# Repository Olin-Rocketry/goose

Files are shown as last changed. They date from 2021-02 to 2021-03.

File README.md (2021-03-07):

# G.O.O.S.E
**G**reat **O**verview **O**f **S**TM **E**lectronics

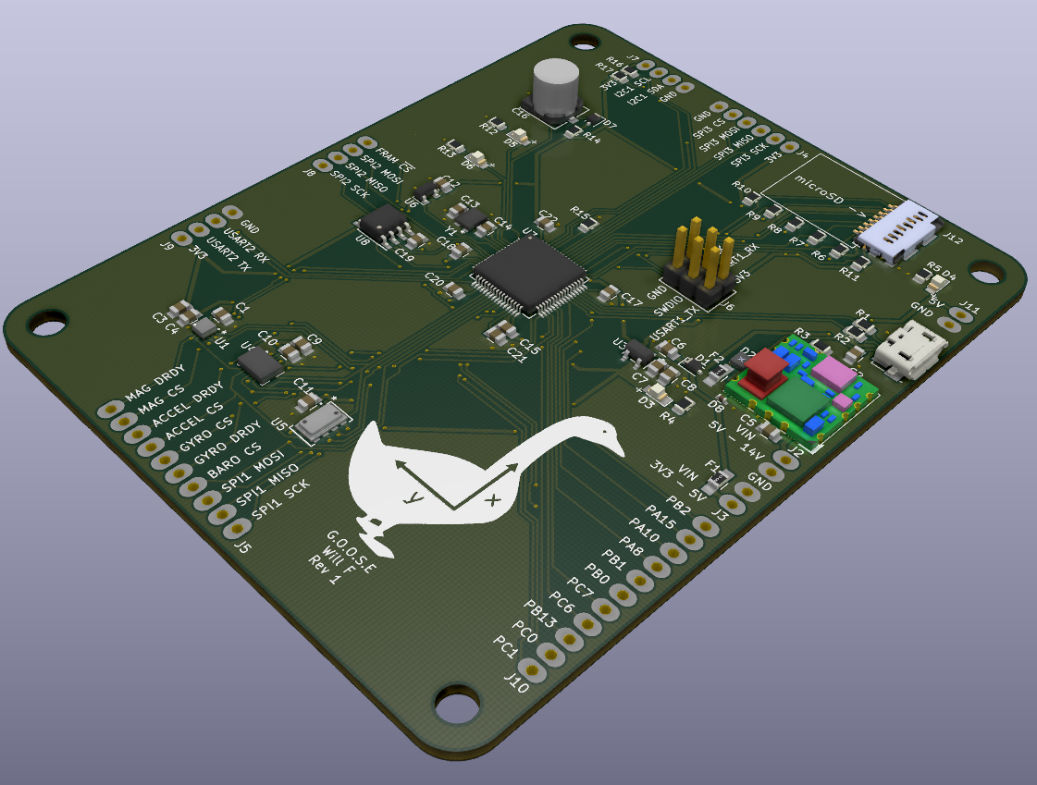
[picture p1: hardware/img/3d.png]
3d render


The overarching goal of this project is to establish the foundation for designing and coding boards with more advanced stm32f-series microcontrollers. These microcontrollers are arm-based, super common in industry and hobbyist projects, have a large community of support, and a ton of features avr chips don't have like:
- usb support
- real time clocks
- high clock speeds (>100Mhz)
- SDIO communication support
- debugging ports
- Direct Memory Access (DMA)

## Development Board
As a development board the primary focus is on testing new hardware (stm32, sensors, power-converts, communication lines, memory, etc). As a result, this board has a ton of pinouts for direct access to almost every pin on the stm32 and all of the communication ports. This board also has a wide voltage input range (3V3 to 14V) in order to allow for a variety of input sources (power supply, battery, usb port, etc). The following is a list of key components on the board.

- **Microcontroller**
	- STM32F401RCT6
- **Sensors**
	- IMU--BMI088
	- Magnetometer--LIS3MDLTR
	- Barometer--MS560702BA03-50
- **Non-Volatile Memory**
	- FM25L04B-G
- **Connection**
	- Micro-SD
	- Debugging/Programming Port 
	- Micro-USB
	- SPI, I2C, UART pinouts
	- Other pinouts
- **Power**
	- Input
		- 3V3 to 14V
	- Output
		- 5V (buck converter)
		- 3V3 (Low Droput Regulator)

## Schematic
The full schematic pdf view can be viewed [here](/hardware/dev_board.pdf)



## Kicad Parts & Footprints
Currently, most of the parts and footprints are located in a [personal library](https://github.com/wFairmanOlin/kicad_parts). I will transition the necessary files to the olin rocketry library when the project is closer to completion.

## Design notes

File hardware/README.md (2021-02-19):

## Accessing Parts Folder 

For now, if you want to access the parts for this board, clone this [repo](https://github.com/wFairmanOlin/kicad_parts) and add a path pointing to `personal.lib` similar to this:

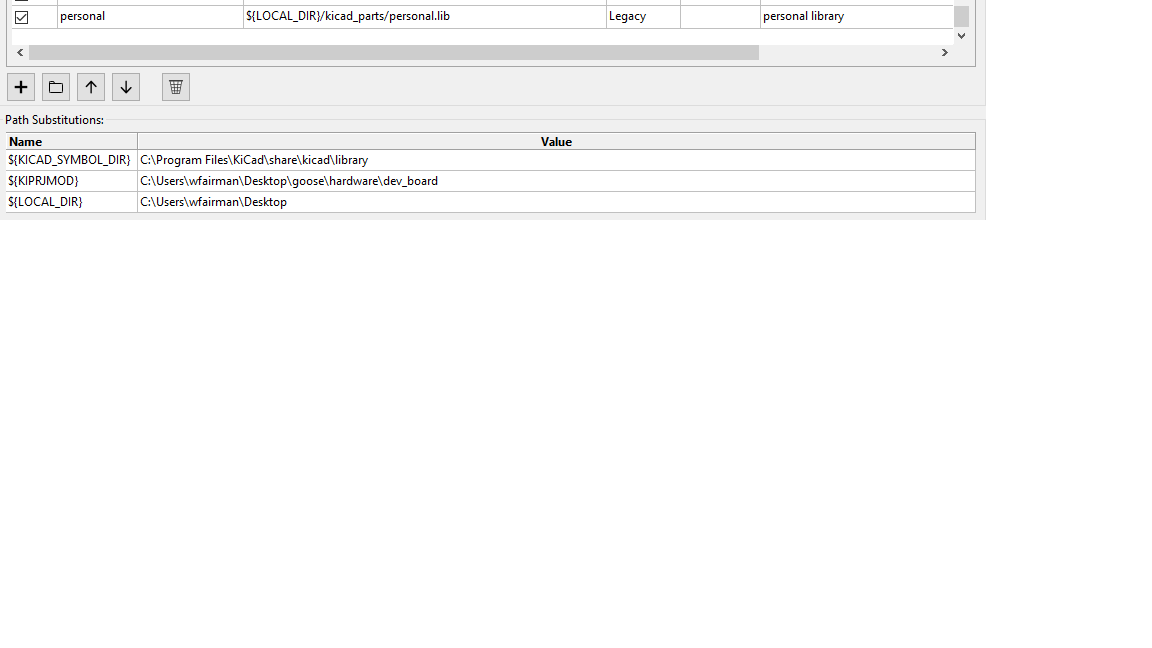
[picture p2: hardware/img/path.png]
path


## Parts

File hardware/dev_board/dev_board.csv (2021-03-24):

Designator | Quantity | Comment | Footprint | MPN | DPN
C13 C14 | 2 | C_8p | C_0805 | CC0805DRNPO9BN8R0 | 311-1097-1-ND
C16 | 1 | C_220u | UWT0G221MCL6GS | UWT0G221MCL6GS | 493-9872-1-ND
C15 C17 | 2 | C_4u7 | C_0805 | GRM21BR71C475KE51L | 490-14466-1-ND
C1 C2 C4 C8 C9 C10 C11 C12 C18 C19 C20 C21 C22 | 13 | C_0u1 | C_0805 | 08055C104JAT2A | 478-3352-1-ND
C3 | 1 | C_1u | C_0805 | C0805C105Z4VACTU | 399-8011-1-ND
C5 | 1 | C_22u | C_0805 | GRM21BR61E226ME44K | 490-14661-1-ND
C6 C7 | 2 | C_10u | C_0805 | GRM21BR61E106KA73K | 490-16824-1-ND
D2 | 1 | D_Schottky_x2_20V | SOT1061 | PMEG2020CPA,115 | 1727-5194-1-ND
D3 D4 D5 D6 | 4 | LED_0805_Green | LED_0805 | LG R971-KN-1 | 475-1410-1-ND
D1 D7 | 2 | D_Schottky_10V_3A | D_SOD-323F | PMEG1030EJ,115 | 1727-3852-1-ND
D8 | 1 | TVS_DIODE_14V | C_0402 | PESD0402-140 | PESD0402-140CT-ND
F1 F2 | 2 | PTC_6V_1A | R_0805 | 0ZCK0050FF2E | 507-1813-1-ND
J1 | 1 | Micro_USB | Molex_47346-0001 | 473460001 | WM17141CT-ND
J10 | 1 | Conn_01x11 | none | none | none
J12 | 1 | 105162-0001 | 105162-0001 | 1051620001 | WM14405CT-ND
J2 J3 J11 | 3 | do not populate | none | none | none
J4 | 1 | do not populate | none | none | none
J5 | 1 | do not populate | none | none | none
J6 | 1 | Conn_02x03 | TSW-103-07-F-D | TSW-103-07-F-D | SAM10846-ND
J7 J8 J9 | 3 | do not populate | none | none | none
R1 R2 | 2 | R_22 | R_0805 | CR0805-FX-22R0ELF | CR0805-FX-22R0ELFCT-ND
R14 | 1 | R_1K | R_0805 | RC0805JR-071KL | 311-1.0KARCT-ND
R15 R16 R17 | 3 | R_10K | R_0805 | RC0805FR-0710KL | 311-10.0KCRCT-ND
R3 | 1 | R_2K18 | R_0805 | RT0805BRD072K18L | 13-RT0805BRD072K18LCT-ND
R4 R12 R13 | 3 | R_51.1 | R_0805 | RMCF0805FT51R1 | RMCF0805FT51R1CT-ND
R5 | 1 | R_120 | R_0805 | CRGCQ0805F120R | A129738CT-ND
R6 R7 R8 R9 R10 R11 | 6 | R_100K | R_0805 | RC0805FR-07100KL | 311-100KCRCT-ND
U1 | 1 | LIS3MDLTR | LIS3MDLTR | LIS3MDLTR | 497-13892-1-ND
U2 | 1 | OKL-T_1-W12P-C | OKL-T1-W12P-C | OKL-T/1-W12P-C | 811-3418-1-ND
U3 | 1 | LDO_600MA | SOT-25_DIO | AP7365-33WG-7 | AP7365-33WG-7DICT-ND
U4 | 1 | BMI088 | BMI088 | BMI088 | 828-1082-1-ND
U5 | 1 | Barometer_MS5607 | MS561101BA03-50 | MS560702BA03-50 | 223-1198-1-ND
U6 | 1 | MCP131T-300E_TT | SOT-23 | MCP131T-300E/TT | MCP131T-300E/TTCT-ND
U7 | 1 | STM32F401RCTx | LQFP-64_10x10mm_P0.5mm | STM32F401RCT6 | 497-14047-ND
U8 | 1 | FRAM_4K | SOIC-8_3.9x4.9mm_Pitch1.27mm | FM25L04B-G | 428-3209-ND
Y1 | 1 | Crystal_24MHZ | STD-CSR-1 | NX3225SA-24.000M-STD-CSR-1 | 644-1052-1-ND

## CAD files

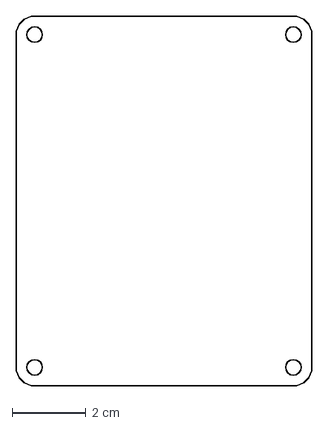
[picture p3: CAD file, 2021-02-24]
hardware/dev_board/circuitBoard v2.dxf
8.00 x 10.0 cm

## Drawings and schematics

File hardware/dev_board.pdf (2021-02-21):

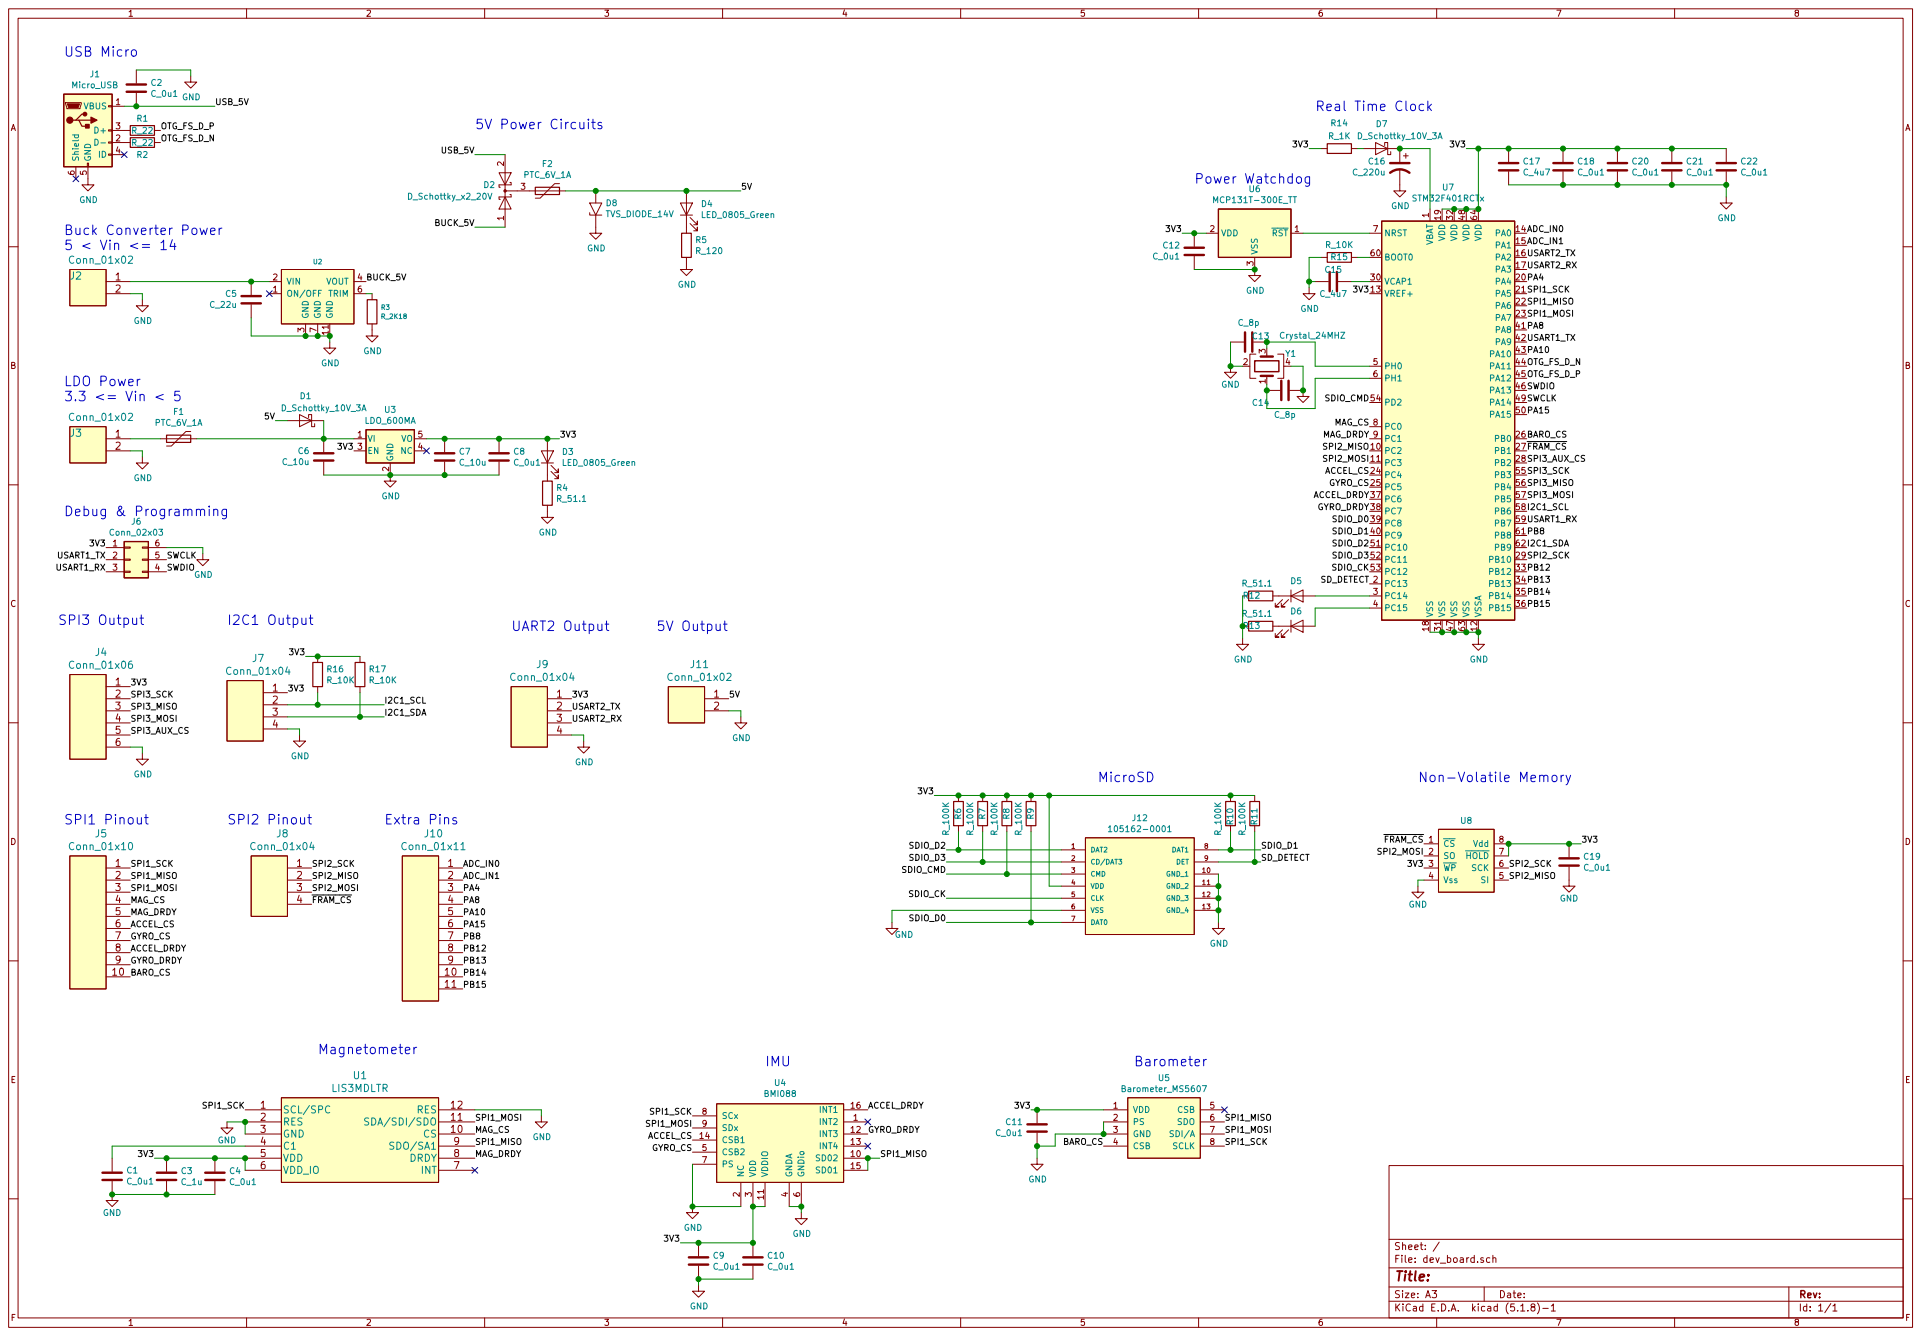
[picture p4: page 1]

1 VCAP1 30 VDD 19 VDD 32 VDD 48 VDD 64 VREF+ 13 VSS 18 VSS 31 VSS 47 VSS 63 VSSA 12 U7 STM32F401RCTx

6 PS 7 SCx 8 SDx 9 U4 BMI088 GND

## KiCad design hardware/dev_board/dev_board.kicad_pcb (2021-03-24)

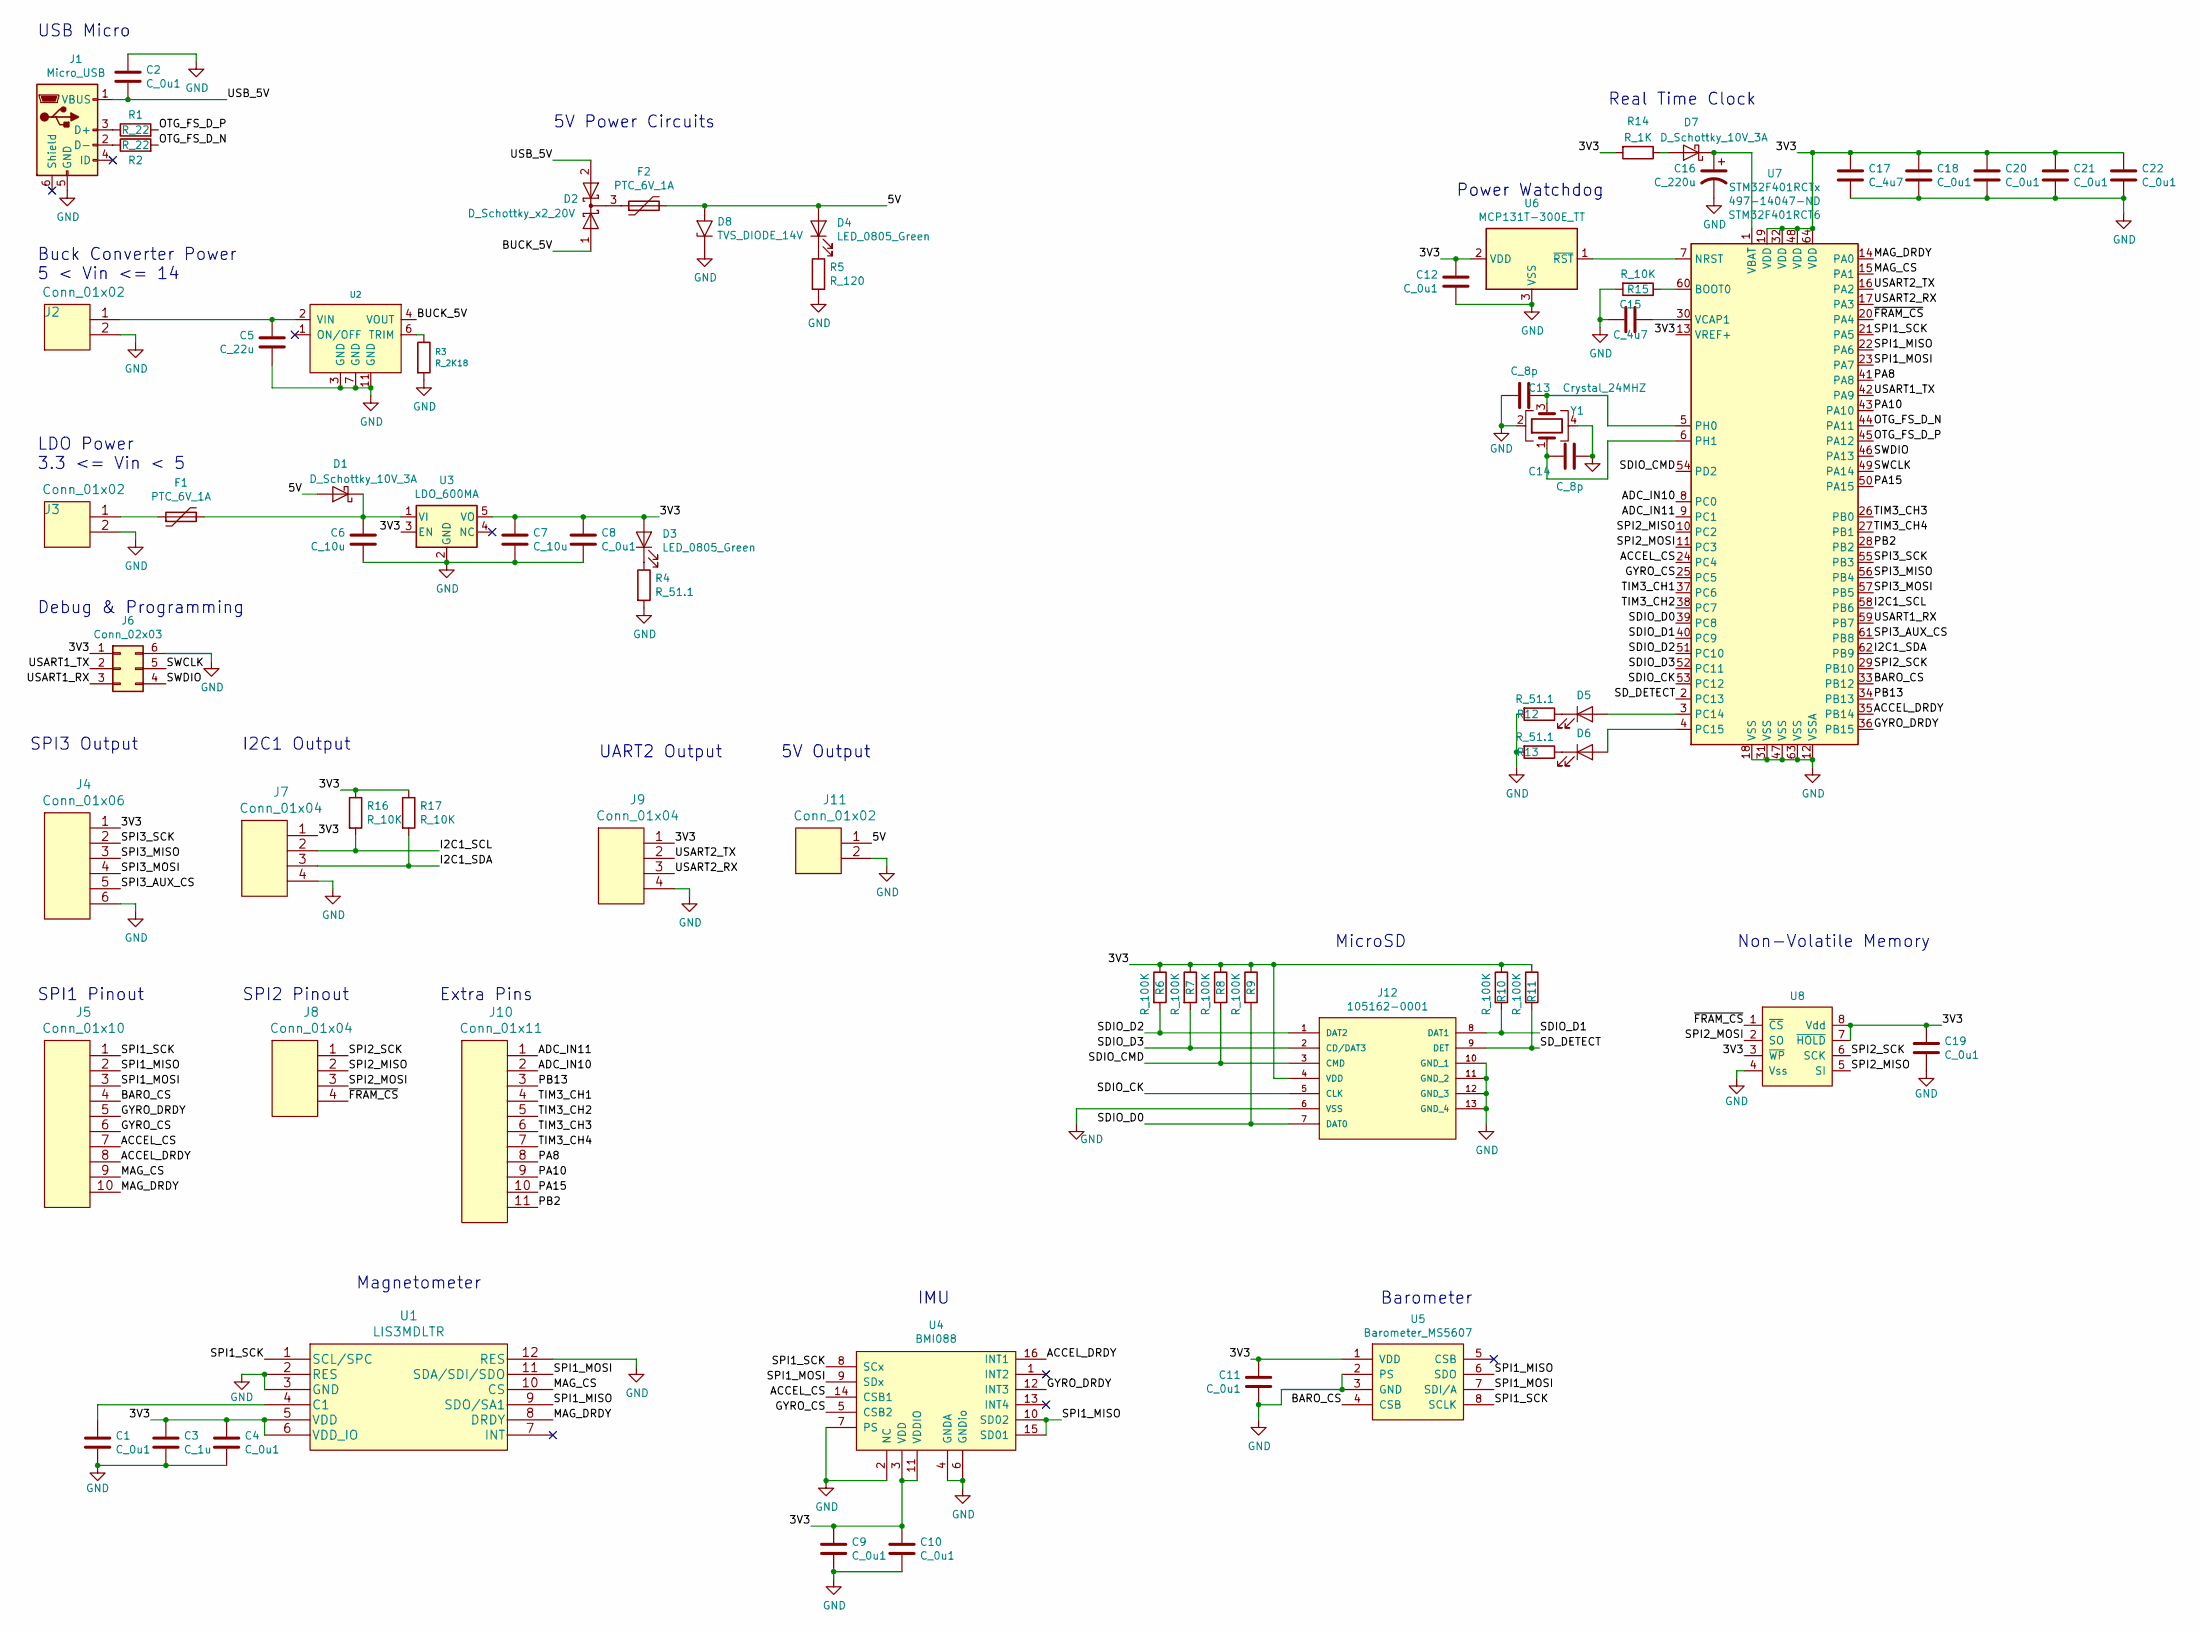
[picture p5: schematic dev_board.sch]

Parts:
C1, C2, C4, C8, C9, C10, C11, C12, C18, C19, C20, C21, C22: C_0u1; C_0805
C3: C_1u; C_0805
C5: C_22u; C_0805
C6, C7: C_10u; C_0805
C13, C14: C_8p; C_0805
C15, C17: C_4u7; C_0805
C16: C_220u; UWT0G221MCL6GS; MPN UWT0G221MCL6GS
D1, D7: D_Schottky_10V_3A; D_SOD-323F; MPN PMEG1030EJ,115
D2: D_Schottky_x2_20V; SOT1061; MPN PMEG2020CPA,115
D3, D4, D5, D6: LED_0805_Green; LED_0805; MPN LG R971-KN-1
D8: TVS_DIODE_14V; C_0402
F1, F2: PTC_6V_1A; R_0805_HandSoldering; MPN 0ZCK0050FF2E
J1: Micro_USB; USB_Micro-B_Molex_47346-0001
J2, J3, J11: Conn_01x02; header_01x02
J4: Conn_01x06; header_01x06
J5: Conn_01x10; header_01x10
J6: Conn_02x03; TSW-103-07-F-D; MPN TSW-103-07-F-D
J7, J8, J9: Conn_01x04; header_01x04
J10: Conn_01x11; header_01x11
J12: 105162-0001; MPN 1051620001
R1, R2: R_22; R_0805; MPN CR0805-FX-22R0ELF
R3: R_2K18; R_0805; MPN RT0805BRD072K18L
R4, R12, R13: R_51.1; R_0805; MPN RMCF0805FT51R1
R5: R_120; R_0805
R6, R7, R8, R9, R10, R11: R_100K; R_0805; MPN RC0805FR-07100KL
R14: R_1K; R_0805
R15, R16, R17: R_10K; R_0805; MPN RC0805FR-0710KL
U1: LIS3MDLTR
U2: OKL-T_1-W12P-C; OKL-T1-W12P-C; MPN OKL-T/1-W12P-C
U3: LDO_600MA; SOT-25_DIO; MPN AP7365-33WG-7
U4: BMI088
U5: Barometer_MS5607; MS561101BA03-50; MPN MS560702BA03-50
U6: MCP131T-300E_TT; SOT-23
U7: STM32F401RCTx; LQFP-64_10x10mm_Pitch0.5mm; MPN STM32F401RCT6
U8: FRAM_4K; SOIC-8_3.9x4.9mm_Pitch1.27mm; MPN FM25L04B-G
Y1: Crystal_24MHZ; NX3225SA-24.000M-STD-CSR-1; MPN NX3225SA-24.000M-STD-CSR-1

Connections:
/3V3: C3.1, C4.1, C7.1, C8.1, C9.1, C10.1, C11.2, C12.2, C17.1, C18.1, C19.1, C20.1, C21.1, C22.1, D3.2 (A), J4.1, J6.1, J7.1, J9.1, J12.4 (VDD), R6.1, R7.1, R8.1, R9.1, R10.1, R11.1, R14.2, R16.1, R17.1, U1.5 (VDD), U1.6 (VDD_IO), U3.3 (EN), U3.5 (VO), U4.3 (VDD), U4.11 (VDDIO), U5.1 (VDD), U6.2 (VDD), U7.13 (VREF+), U7.19 (VDD), U7.32 (VDD), U7.48 (VDD), U7.64 (VDD), U8.3 (~WP), U8.7 (~HOLD), U8.8 (Vdd)
/5V: D1.2 (A), D4.2 (A), D8.2 (A2), F2.2, J11.1
/ACCEL_CS: J5.7, U4.14 (CSB1), U7.24 (PC4)
/ACCEL_DRDY: J5.8, U4.16 (INT1), U7.35 (PB14)
/ADC_IN10: J10.2, U7.8 (PC0)
/ADC_IN11: J10.1, U7.9 (PC1)
/BARO_CS: J5.4, U5.4 (CSB), U7.33 (PB12)
/BUCK_5V: D2.1 (A), U2.4 (VOUT)
/GYRO_CS: J5.6, U4.5 (CSB2), U7.25 (PC5)
/GYRO_DRDY: J5.5, U4.12 (INT3), U7.36 (PB15)
/I2C1_SCL: J7.2, R16.2, U7.58 (PB6)
/I2C1_SDA: J7.3, R17.2, U7.62 (PB9)
/MAG_CS: J5.9, U1.10 (CS), U7.15 (PA1)
/MAG_DRDY: J5.10, U1.8 (DRDY), U7.14 (PA0)
/OTG_FS_D_N: R2.2, U7.44 (PA11)
/OTG_FS_D_P: R1.2, U7.45 (PA12)
/PA8: J10.8, U7.41 (PA8)
/PA10: J10.9, U7.43 (PA10)
/PA15: J10.10, U7.50 (PA15)
/PB2: J10.11, U7.28 (PB2)
/PB13: J10.3, U7.34 (PB13)
/SDIO_CK: J12.5 (CLK), U7.53 (PC12)
/SDIO_CMD: J12.3 (CMD), R8.2, U7.54 (PD2)
/SDIO_D0: J12.7 (DAT0), R9.2, U7.39 (PC8)
/SDIO_D1: J12.8 (DAT1), R10.2, U7.40 (PC9)
/SDIO_D2: J12.1 (DAT2), R6.2, U7.51 (PC10)
/SDIO_D3: J12.2 (CD/DAT3), R7.2, U7.52 (PC11)
/SD_DETECT: J12.9 (DET), R11.2, U7.2 (PC13)
/SPI1_MISO: J5.2, U1.9 (SDO/SA1), U4.10 (SD02), U4.15 (SD01), U5.6 (SDO), U7.22 (PA6)
/SPI1_MOSI: J5.3, U1.11 (SDA/SDI/SDO), U4.9 (SDx), U5.7 (SDI/A), U7.23 (PA7)
/SPI1_SCK: J5.1, U1.1 (SCL/SPC), U4.8 (SCx), U5.8 (SCLK), U7.21 (PA5)
/SPI2_MISO: J8.2, U7.10 (PC2), U8.5 (SI)
/SPI2_MOSI: J8.3, U7.11 (PC3), U8.2 (SO)
/SPI2_SCK: J8.1, U7.29 (PB10), U8.6 (SCK)
/SPI3_AUX_CS: J4.5, U7.61 (PB8)
/SPI3_MISO: J4.3, U7.56 (PB4)
/SPI3_MOSI: J4.4, U7.57 (PB5)
/SPI3_SCK: J4.2, U7.55 (PB3)
/SWCLK: J6.5, U7.49 (PA14)
/SWDIO: J6.4, U7.46 (PA13)
/TIM3_CH1: J10.4, U7.37 (PC6)
/TIM3_CH2: J10.5, U7.38 (PC7)
/TIM3_CH3: J10.6, U7.26 (PB0)
/TIM3_CH4: J10.7, U7.27 (PB1)
/USART1_RX: J6.3, U7.59 (PB7)
/USART1_TX: J6.2, U7.42 (PA9)
/USART2_RX: J9.3, U7.17 (PA3)
/USART2_TX: J9.2, U7.16 (PA2)
/USB_5V: C2.2, D2.2 (A), J1.1 (VBUS)
/~FRAM_CS: J8.4, U7.20 (PA4), U8.1 (~CS)
GND: C1.1, C2.1, C3.2, C4.2, C5.1, C6.1, C7.2, C8.2, C9.2, C10.2, C11.1, C12.1, C13.2, C14.1, C15.2, C16.2, C17.2, C18.2, C19.2, C20.2, C21.2, C22.2, D8.1 (A1), J1.5 (GND), J2.2, J3.2, J4.6, J6.6, J7.4, J9.4, J11.2, J12.6 (VSS), J12.10 (GND_1), J12.11 (GND_2), J12.12 (GND_3), J12.13 (GND_4), R3.2, R4.2, R5.2, R12.2, R13.2, R15.2, U1.2 (RES), U1.3 (GND), U1.12 (RES), U2.3 (GND), U2.7 (GND), U2.11 (GND), U3.2 (GND), U4.2 (NC), U4.4 (GNDA), U4.6 (GNDio), U4.7 (PS), U5.2 (PS), U5.3 (GND), U6.3 (VSS), U7.12 (VSSA), U7.18 (VSS), U7.31 (VSS), U7.47 (VSS), U7.63 (VSS), U8.4 (Vss), Y1.2, Y1.4
unnamed: C1.2, U1.4 (C1)
unnamed: C5.2, J2.1, U2.2 (VIN)
unnamed: C6.2, D1.1 (K), F1.2, U3.1 (VI)
unnamed: C13.1, U7.5 (PH0), Y1.3
unnamed: C14.2, U7.6 (PH1), Y1.1
unnamed: C15.1, U7.30 (VCAP1)
unnamed: C16.1, D7.1 (K), U7.1 (VBAT)
unnamed: D2.3 (K), F2.1
unnamed: D3.1 (K), R4.1
unnamed: D4.1 (K), R5.1
unnamed: D5.1 (K), R12.1
unnamed: D5.2 (A), U7.3 (PC14)
unnamed: D6.1 (K), R13.1
unnamed: D6.2 (A), U7.4 (PC15)
unnamed: D7.2 (A), R14.1
unnamed: F1.1, J3.1
unnamed: J1.2 (D-), R2.1
unnamed: J1.3 (D+), R1.1
unnamed: R3.1, U2.6 (TRIM)
unnamed: R15.1, U7.60 (BOOT0)
unnamed: U6.1 (~RST), U7.7 (NRST)

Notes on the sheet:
Buck Converter Power 5 < Vin <= 14
USB Micro
LDO Power 3.3 <= Vin < 5
Debug & Programming
5V Power Circuits
SPI3 Output
I2C1 Output
UART2 Output
Magnetometer
IMU
Barometer
MicroSD
Non-Volatile Memory
SPI1 Pinout
SPI2 Pinout
Power Watchdog
Real Time Clock
5V Output
Extra Pins

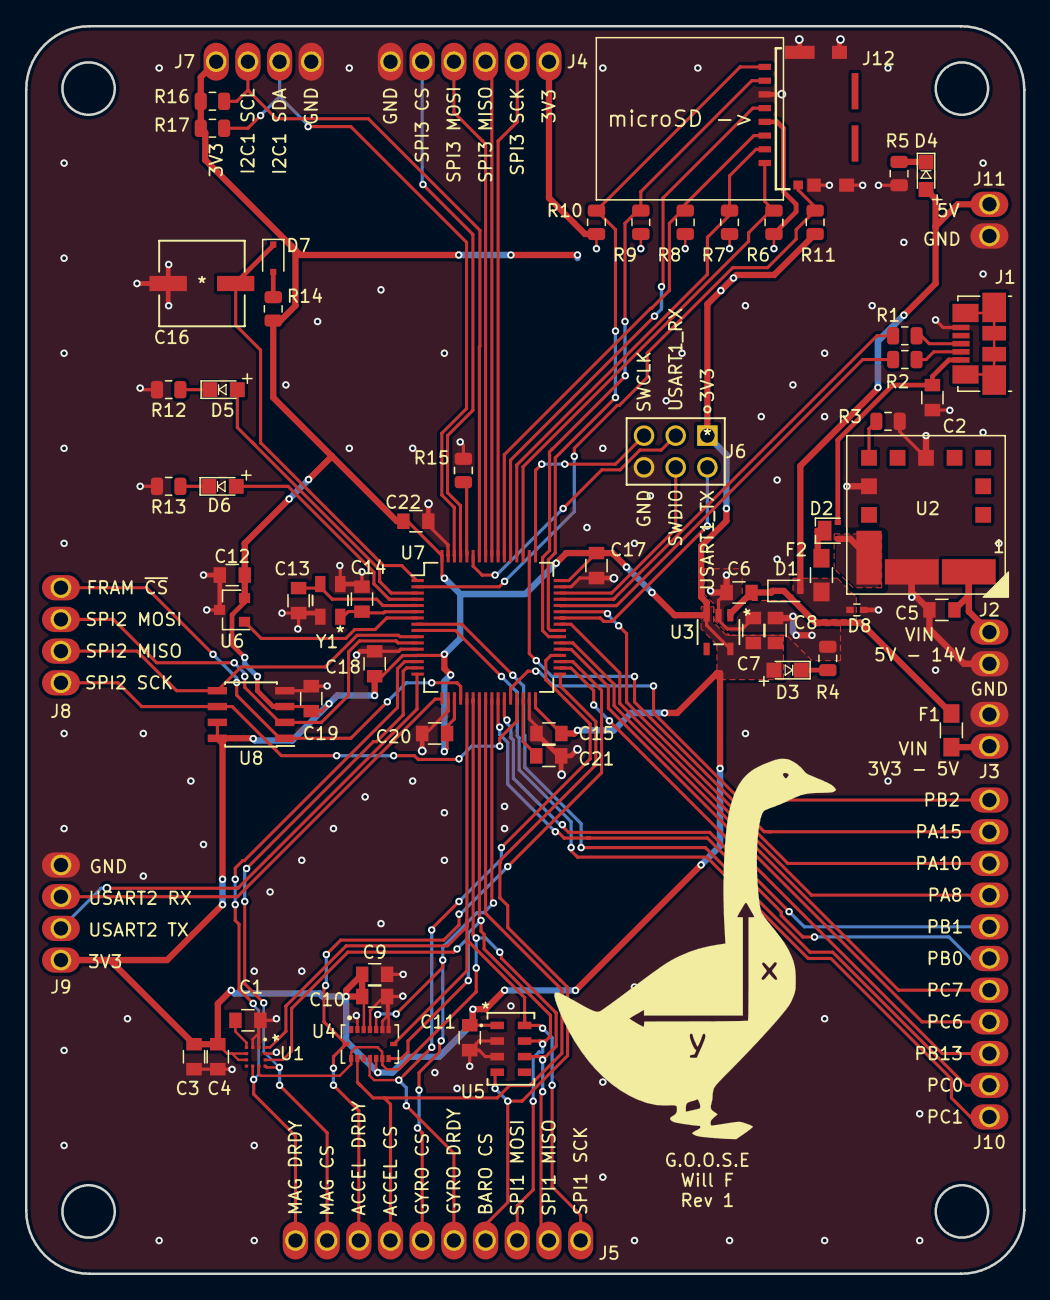
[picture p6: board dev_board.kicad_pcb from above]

Board: 2 copper layers, 80.0 x 100.0 mm, 70 parts (0 on the bottom side), 72 nets.

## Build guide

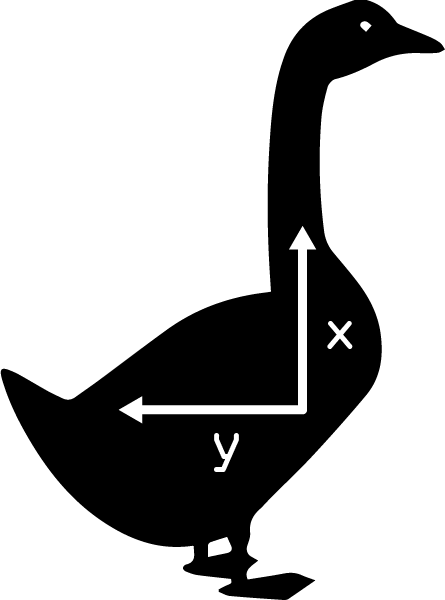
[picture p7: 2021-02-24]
hardware/dev_board/axis_guide.png

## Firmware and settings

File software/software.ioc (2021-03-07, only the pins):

Mcu.UserName=STM32F401RCTx
PA0-WKUP.Signal=GPIO_Input
PA1.Signal=GPIO_Output
PA11.Signal=USB_OTG_FS_DM
PA12.Signal=USB_OTG_FS_DP
PA13.Signal=SYS_JTMS-SWDIO
PA14.Signal=SYS_JTCK-SWCLK
PA2.Signal=USART2_TX
PA3.Signal=USART2_RX
PA4.Signal=GPIO_Output
PA5.Signal=SPI1_SCK
PA6.Signal=SPI1_MISO
PA7.Signal=SPI1_MOSI
PA9.Signal=USART1_TX
PB0.Signal=S_TIM3_CH3
PB1.Signal=S_TIM3_CH4
PB10.Signal=SPI2_SCK
PB12.Signal=GPIO_Output
PB14.Signal=GPIO_Input
PB15.Signal=GPIO_Input
PB3.Signal=SPI3_SCK
PB4.Signal=SPI3_MISO
PB5.Signal=SPI3_MOSI
PB6.Signal=I2C1_SCL
PB7.Signal=USART1_RX
PB8.Signal=GPIO_Output
PB9.Signal=I2C1_SDA
PC0.Signal=ADCx_IN10
PC1.Signal=ADCx_IN11
PC10.Signal=SDIO_D2
PC11.Signal=SDIO_D3
PC12.Signal=SDIO_CK
PC13-ANTI_TAMP.Signal=GPIO_Input
PC14-OSC32_IN.Signal=GPIO_Output
PC15-OSC32_OUT.Signal=GPIO_Output
PC2.Signal=SPI2_MISO
PC3.Signal=SPI2_MOSI
PC4.Signal=GPIO_Output
PC5.Signal=GPIO_Output
PC6.Signal=S_TIM3_CH1
PC7.Signal=S_TIM3_CH2
PC8.Signal=SDIO_D0
PC9.Signal=SDIO_D1
PD2.Signal=SDIO_CMD

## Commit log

2021-02-19 added folders and created kicad project
    [dev_board.kicad_pcb, dev_board.sch]
2021-02-21 finished schematic
    [dev_board.sch]
2021-02-21 Fixed a few errors
    [dev_board.sch]
2021-02-21 fixed power issue with schematic
    [dev_board.sch]
2021-02-24 added the all important axis guide and started layout
    [circuitBoard v2.dxf, dev_board.kicad_pcb, dev_board.sch]
2021-03-07 finished layout
    [dev_board.kicad_pcb, dev_board.sch]
2021-03-07 added more vias
    [dev_board.kicad_pcb]
2021-03-24 added fabrication files
    [dev_board-B_Cu.gbr, dev_board-B_Mask.gbr, dev_board-B_Paste.gbr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]
2021-03-24 added csv
    [dev_board.csv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]

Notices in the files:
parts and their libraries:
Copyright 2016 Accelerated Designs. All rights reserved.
